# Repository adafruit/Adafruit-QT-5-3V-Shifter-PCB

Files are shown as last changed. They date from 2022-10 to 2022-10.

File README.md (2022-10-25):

## Adafruit QT 5-3V Shifter Breakout - STEMMA QT/Qwiic PCB

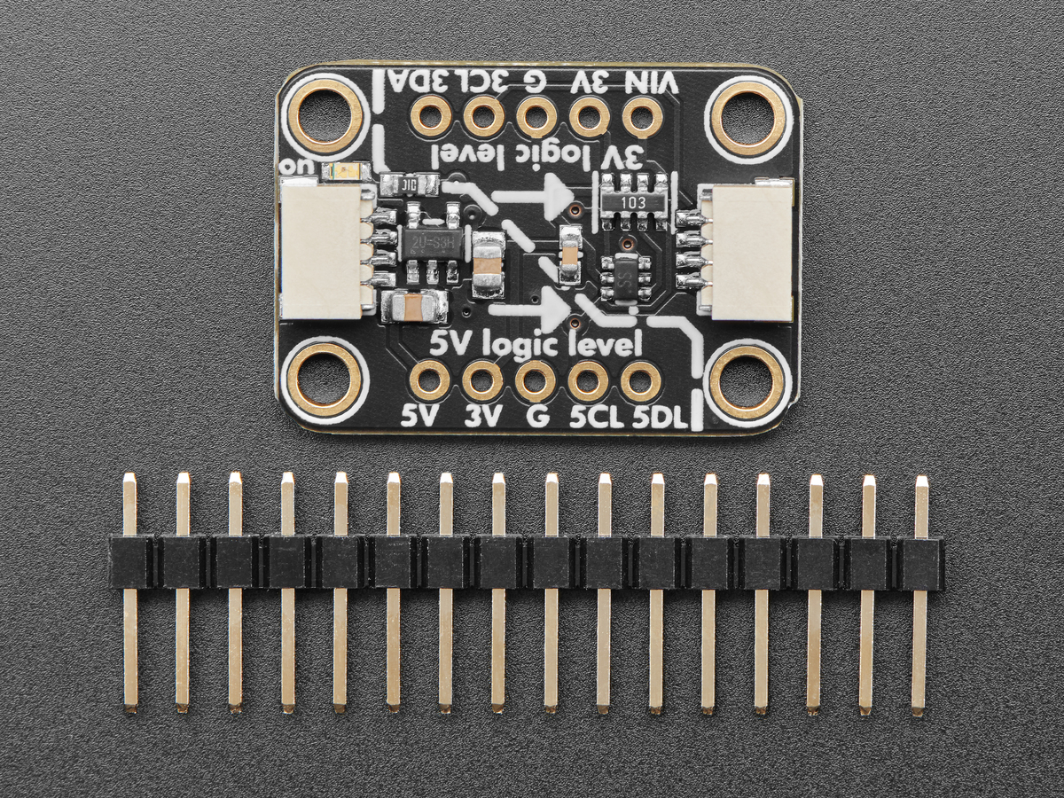
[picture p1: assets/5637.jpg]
<a href="http://www.adafruit.com/products/5637"><br/>
Click here to purchase one from the Adafruit shop</a>

PCB files for the Adafruit QT 5-3V Shifter Breakout - STEMMA QT/Qwiic. 

Format is EagleCAD schematic and board layout
* https://www.adafruit.com/product/5637

### Description

If you're hankerin' to use the new Qwiic / Stemma QT standard for your next project - but you're still using a classic Arduino UNO or other 5V microcontroller, this board is designed for you! Note that Adafruit QT boards are all 3V and 5V safe but many other Qwiic and other I2C devices are not 5V safe or compatible. That means that if you use wires to connect a Qwiic board to a 5V microcontroller you risk damaging your shiny new I2C sensor with over-high voltages. Unless, of course you have one of these Adafruit QT 5V to 3V Shifter Breakouts

On one side is 5V-safe power and logic input. In the middle is a 3.3V regulator that can provide 500mA plus level shifting circuitry. On the opposite side is the same I2C traffic but now safely shifted down to 3.3V to allow usage with the vast number of sensors and devices that are not 5V safe.

It's simple but very effective! You also get breadboard breakout pins for breadboard usage so it can also be used as a QT-to-perfboard adapter.

The STEMMA QT connectors on either side are compatible with the  I2C connectors. This allows you to make solderless connections between your development board and the QT Shifter or to chain it with a wide range of other sensors and accessories using a compatible cable. QT Cable is not included, but we have a variety in the shop.

### License

Adafruit invests time and resources providing this open source design, please support Adafruit and open-source hardware by purchasing products from [Adafruit](https://www.adafruit.com)!

Designed by Limor Fried/Ladyada for Adafruit Industries.

Creative Commons Attribution/Share-Alike, all text above must be included in any redistribution. 
See license.txt for additional details.

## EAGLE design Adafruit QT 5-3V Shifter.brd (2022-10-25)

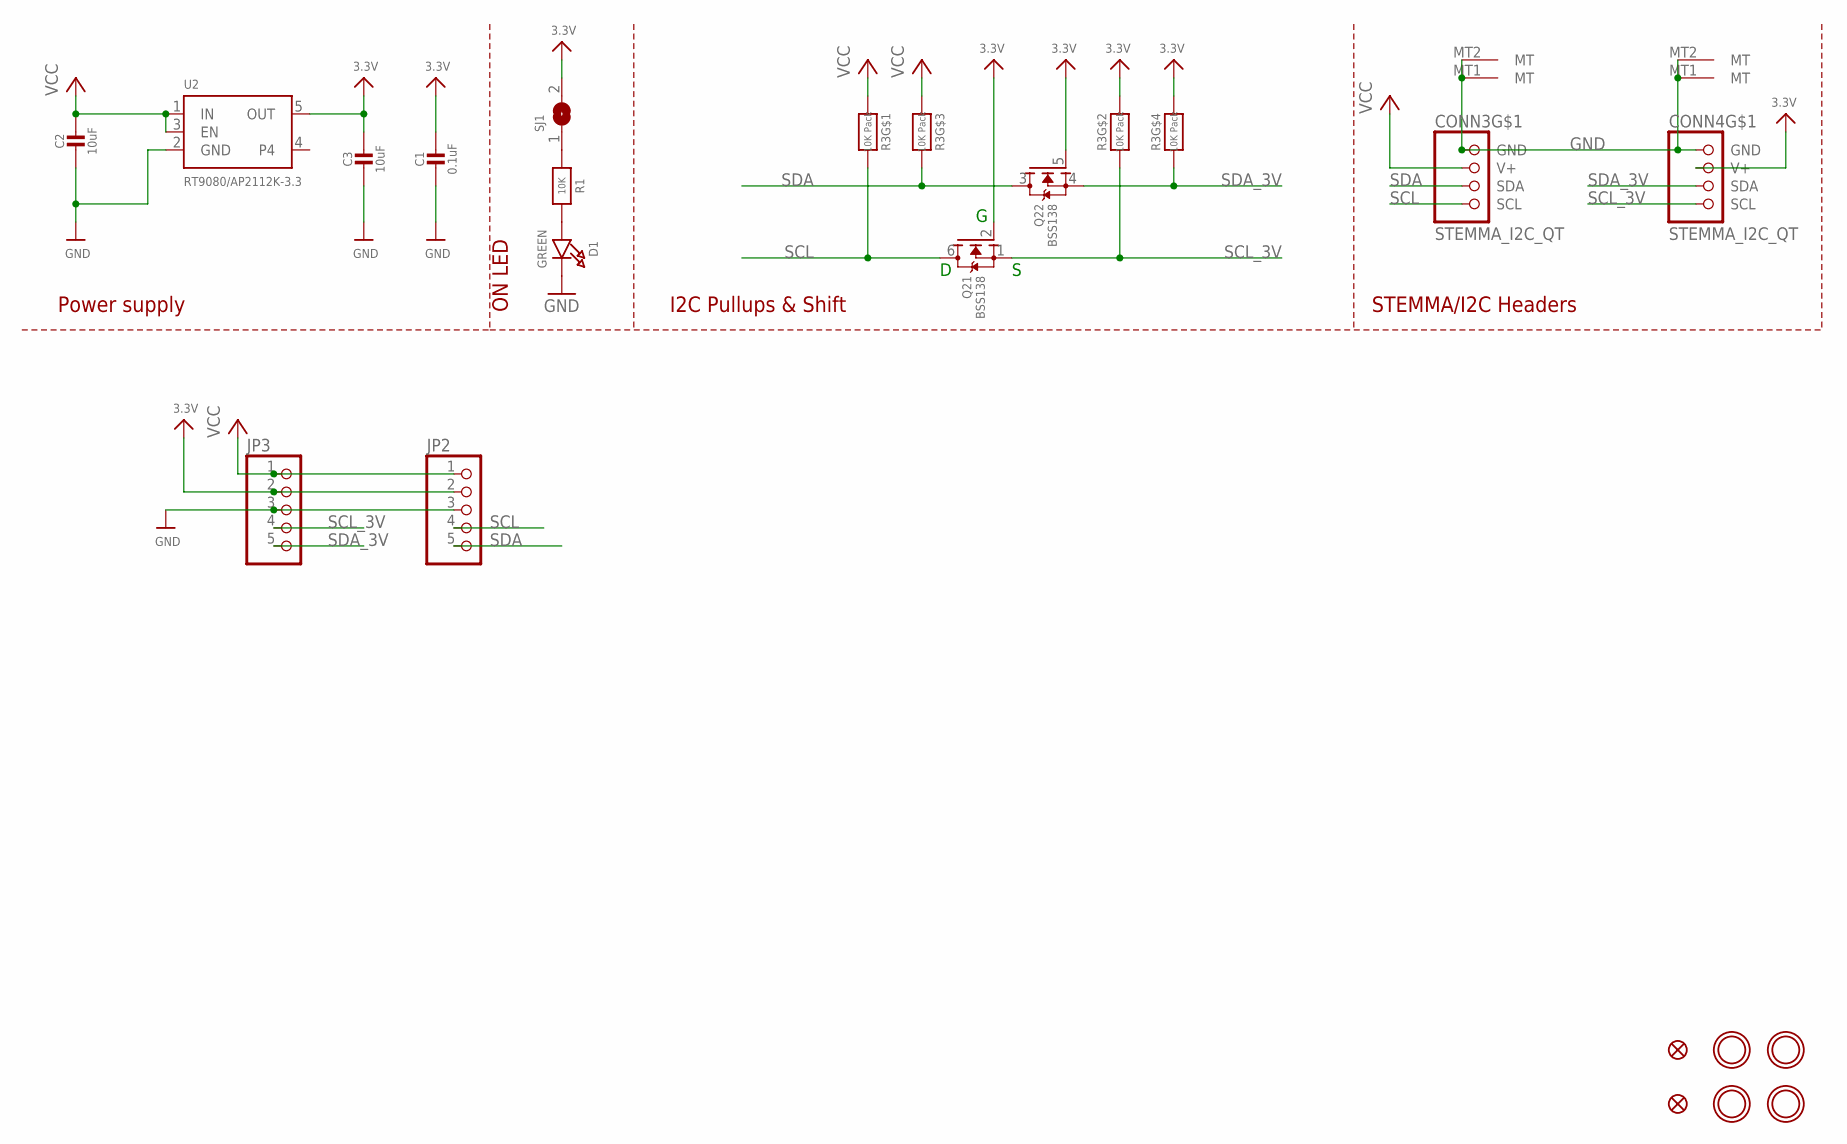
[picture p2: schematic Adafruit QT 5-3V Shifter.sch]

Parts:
C1: 0.1uF; 0603-NO
C2, C3: 10uF; 0805-NO
CONN3, CONN4: STEMMA_I2C_QT; JST_SH4
D1: GREEN; CHIPLED_0603_NOOUTLINE
FID3, FID4: FIDUCIAL_1MM
JP2, JP3: HEADER-1X576MIL; 1X05_ROUND_76
Q2: BSS138; SOT363
R1: 10K; 0603-NO
R3: 10K Pack; RESPACK_4X0603
SJ1: SOLDERJUMPERCLOSED; SOLDERJUMPER_CLOSEDWIRE
U2: RT9080/AP2112K-3.3; SOT23-5; JLC_ROTATION 0
U$1, U$17, U$19, U$21: MOUNTINGHOLE2.5; MOUNTINGHOLE_2.5_PLATED

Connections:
3.3V: C1.1, C3.1, CONN4.2 (V+), JP2.2, JP3.2, Q2.2 (G), Q2.5 (G), R3.2 (1), R3.4 (1), SJ1.2, U2.5 (OUT)
GND: C1.2, C2.2, C3.2, CONN3.1 (GND), CONN3.MT1 (MT), CONN3.MT2 (MT), CONN4.1 (GND), CONN4.MT1 (MT), CONN4.MT2 (MT), D1.C, JP2.3, JP3.3, U2.2 (GND)
unnamed: D1.A, R1.2
unnamed: R1.1, SJ1.1
SCL: CONN3.4 (SCL), JP2.4, Q2.6 (D), R3.8 (2)
SCL_3V: CONN4.4 (SCL), JP3.4, Q2.1 (S), R3.7 (2)
SDA: CONN3.3 (SDA), JP2.5, Q2.3 (D), R3.6 (2)
SDA_3V: CONN4.3 (SDA), JP3.5, Q2.4 (S), R3.5 (2)
VCC: C2.1, CONN3.2 (V+), JP2.1, JP3.1, R3.1, R3.3 (1), U2.1 (IN), U2.3 (EN)

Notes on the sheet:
I2C Pullups & Shift
STEMMA/I2C Headers
ON LED
Power supply

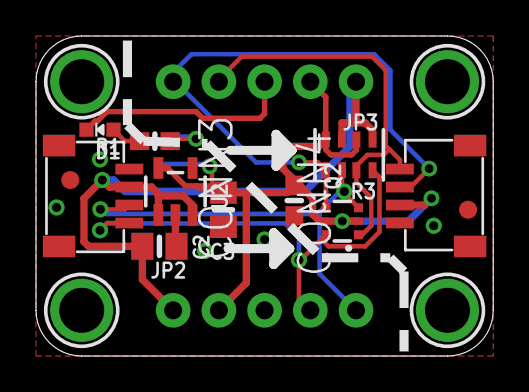
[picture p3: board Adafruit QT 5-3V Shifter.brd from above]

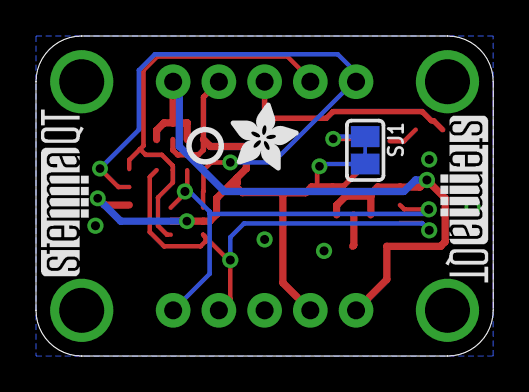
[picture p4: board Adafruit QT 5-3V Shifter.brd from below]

Board: 2 copper layers, 25.4 x 17.8 mm, 38 parts (7 on the bottom side), 9 nets.

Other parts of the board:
PLABEL0: PLABEL0
PLABEL1: PLABEL1
PLABEL2: PLABEL2
PLABEL3: PLABEL3
PLABEL4: PLABEL4
PLABEL5: PLABEL5
PLABEL6: PLABEL6
PLABEL7: PLABEL7
PLABEL8: PLABEL8
PLABEL9: PLABEL9
PLABEL10: PLABEL10
PLABEL11: PLABEL11
PLABEL12: PLABEL12
PLABEL13: PLABEL13
PLABEL14: PLABEL14
U$2: ADAFRUIT_3.5MM
U$25: PCBFEAT-REV-040
U$30, U$31: STEMMAQT

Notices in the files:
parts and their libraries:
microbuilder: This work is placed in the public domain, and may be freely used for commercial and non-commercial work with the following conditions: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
